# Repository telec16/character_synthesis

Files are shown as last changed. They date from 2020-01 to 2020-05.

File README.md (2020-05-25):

# Character Synthesis using Fourier Transform

Based on http://www.glensstuff.com/fouriersynthchargen/fouriersynthchargen.htm

## Front Panel

The front panel was made with Galva ( http://www.f5bu.fr/galva-download/ ), in French.

## Clock generation board

~/!\ DIVoddN is not synthetizable with Lattice LSE. I use Synplify Pro.~ Actually I don't know what's going on, but it does not correspond to the simulation. The hardware tests show no errors.

### FPGA pinmap

| Name 		| Pin Number | Pin Name | Location  |
|---|---|---|---|
| clk_1M2	| 13		 | PCLKT2_1	| X1.3		|
| clrn		| 14		 | PCLKC2_1	| J4.1		|
| clk_20k	| 8			 | CSSPIN	| J2.5		|
| clk_40k	| 9			 | MCLK		| J2.4		|
| clk_60k	| 10		 | SPISO	| J2.3		|
| clk_80k	| 11		 | PCLKT2_0	| J2.2		|
| clk_100k	| 12		 | PCLKC2_0	| J2.1		|
| E1A		| 16		 | SN		| SW1.1		|
| E1B		| 17		 | SPISI	| SW1.3		|
| E2A		| 20		 | PCLKC1_0	| SW2.1		|
| E2B		| 21		 | PCLKT1_0	| SW2.3		|
| blanking  | 5			 | PCLKC3_0	| J2.6		|
| led 		| 23		 | DONE		| D2		|
| pin1		| 28		 | SCL		| J2.8		|
| pin2		| 4			 | PCLKT3_0	| J2.7		|
| TDO		| 1			 | TDO		| J1.5		|
| TDI		| 32		 | TDI		| J1.3		|
| TCK		| 30		 | TCK		| J1.2		|
| TMS		| 29		 | TMS		| J1.1		|

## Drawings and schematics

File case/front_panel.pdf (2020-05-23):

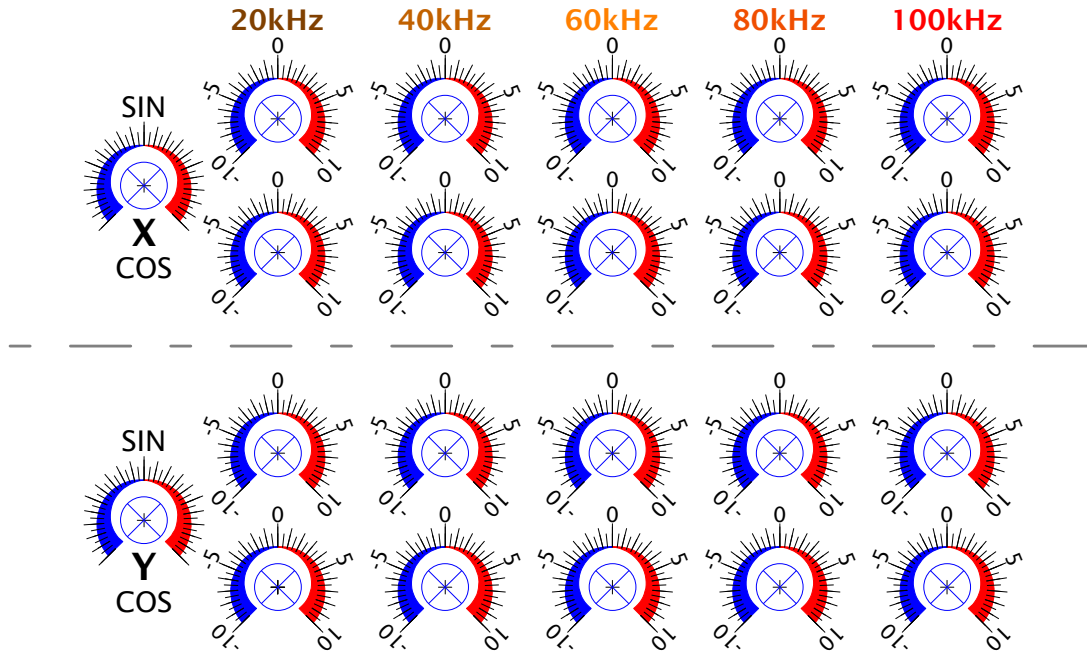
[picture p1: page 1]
20kHz; 40kHz; 60kHz; 80kHz; 100kHz; SIN; COS

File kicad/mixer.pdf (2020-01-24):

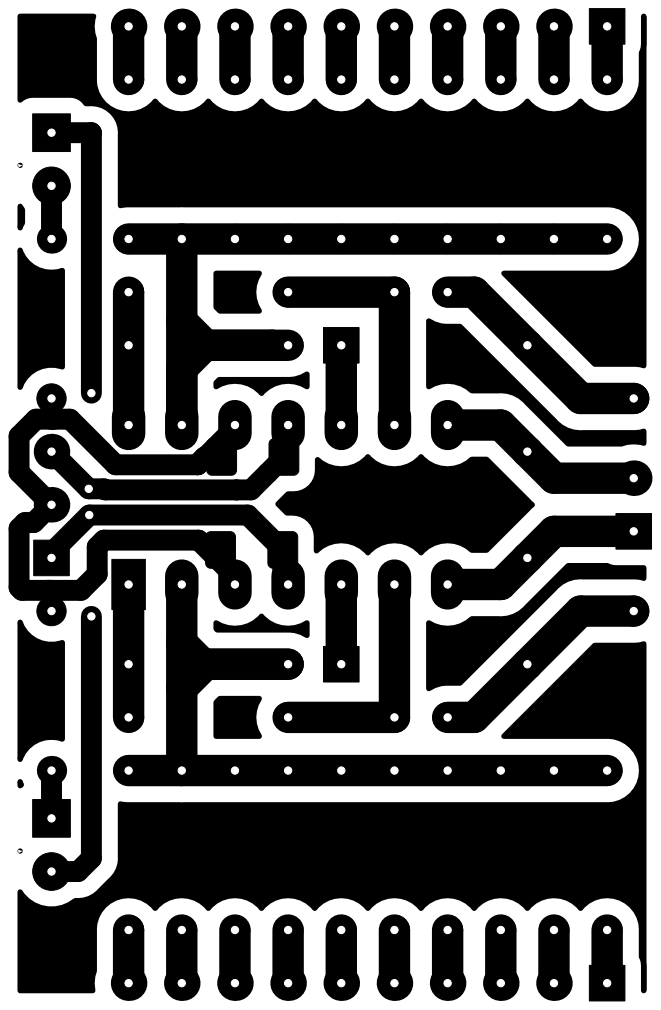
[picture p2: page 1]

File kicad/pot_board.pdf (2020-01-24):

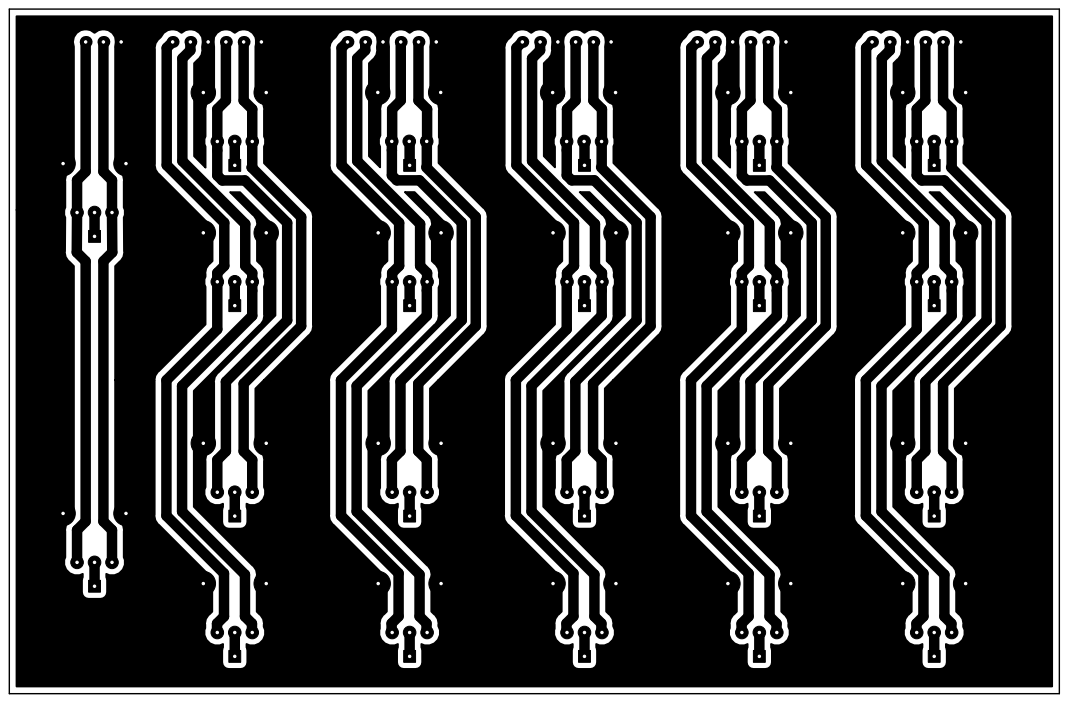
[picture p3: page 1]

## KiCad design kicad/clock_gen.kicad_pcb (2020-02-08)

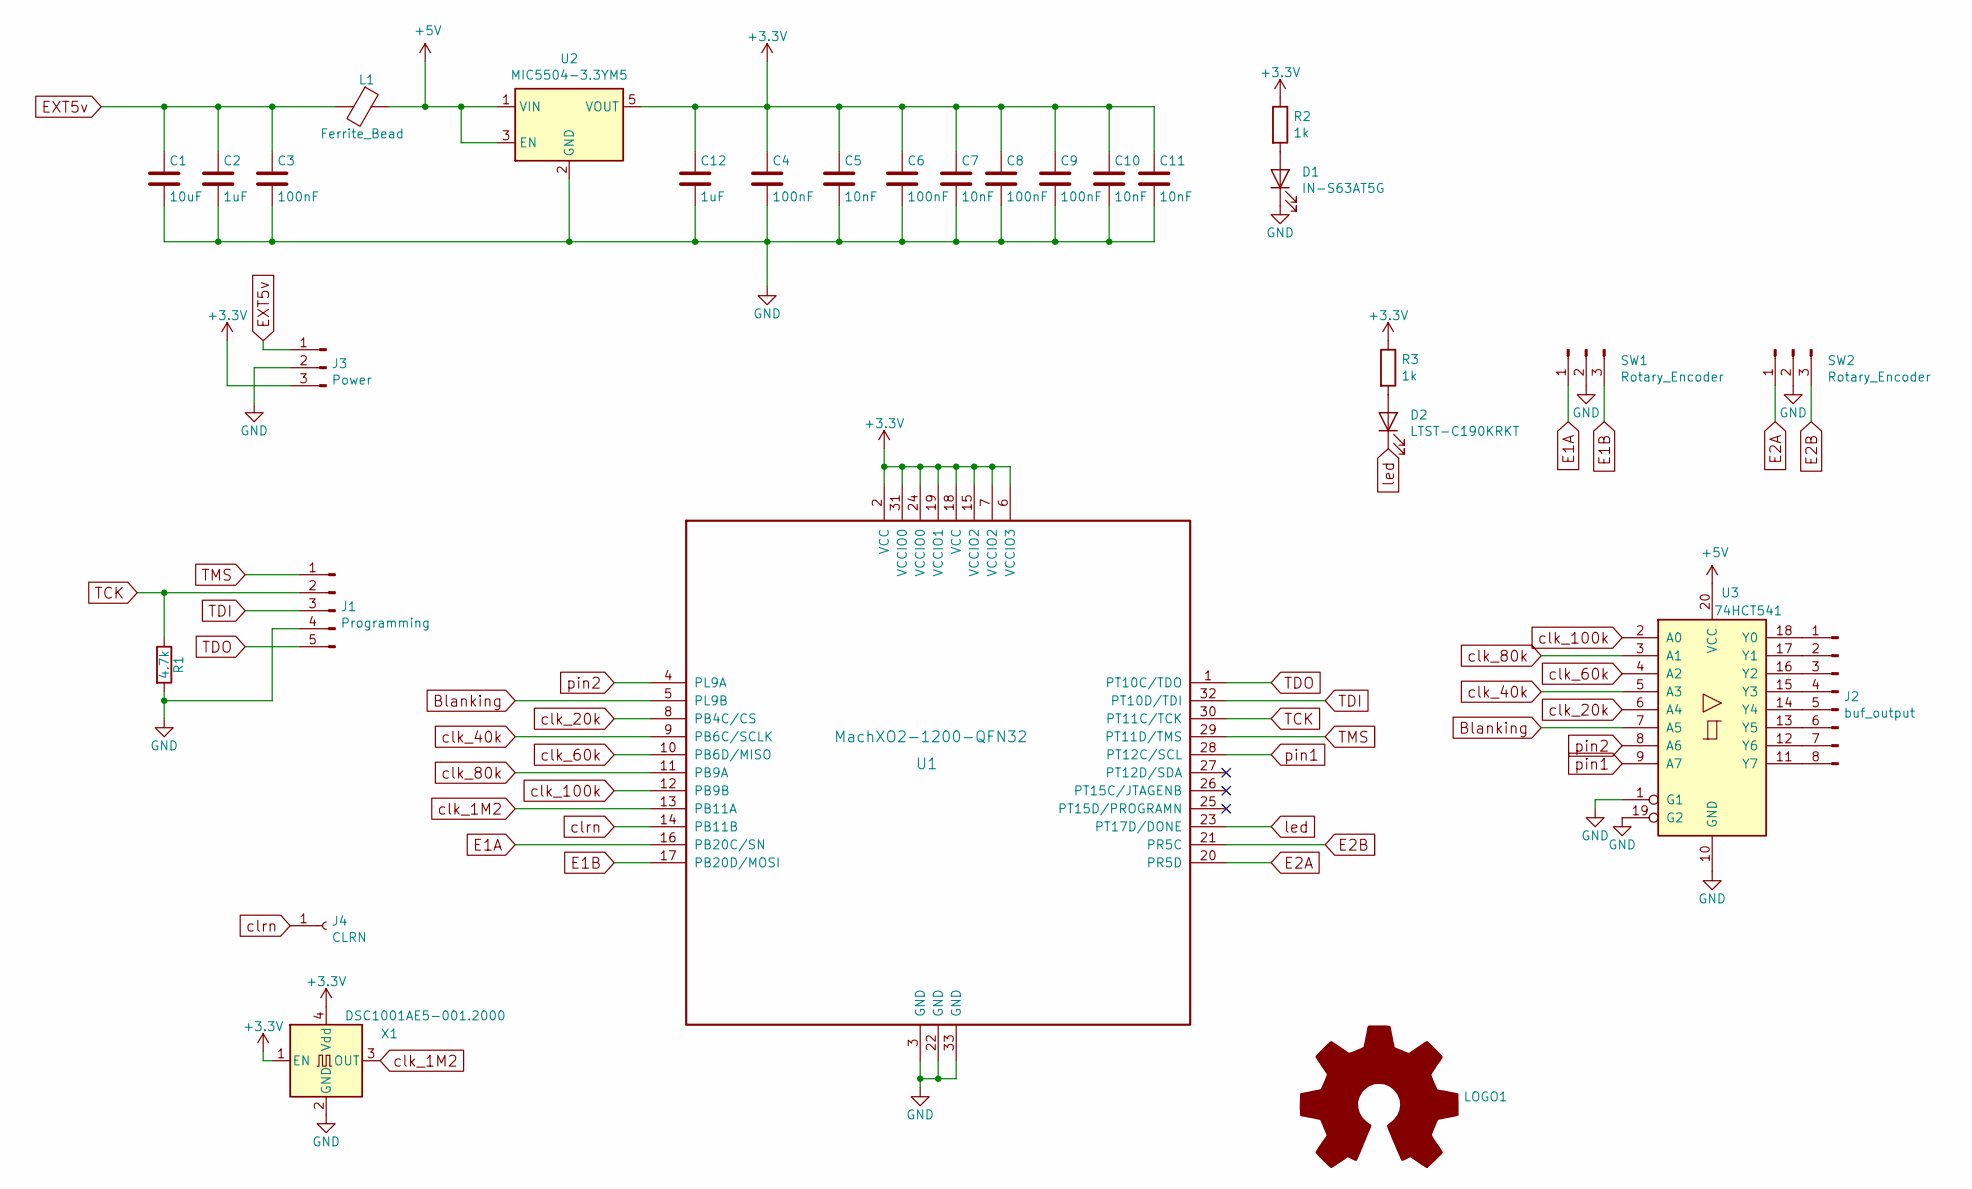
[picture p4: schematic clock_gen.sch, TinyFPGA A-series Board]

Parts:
C1: 10uF; C_0603_1608Metric
C2, C12: 1uF; C_0603_1608Metric
C3, C4, C6, C8, C9: 100nF; C_0603_1608Metric
C5, C7, C10, C11: 10nF; C_0603_1608Metric
D1: IN-S63AT5G; LED_0603_1608Metric
D2: LTST-C190KRKT; LED_0603_1608Metric
J1: Programming; PinHeader_1x05_P2.54mm_Vertical
J2: buf_output; PinHeader_1x08_P1.27mm_Vertical
J3: Power; PinHeader_1x03_P1.27mm_Vertical
J4: CLRN; PinHeader_1x01_P1.27mm_Vertical
L1: Ferrite_Bead; L_0603_1608Metric
LOGO1: Logo_Open_Hardware_Large; clk
R1: 4.7k; R_0603_1608Metric
R2, R3: 1k; R_0603_1608Metric
SW1, SW2: Rotary_Encoder; PinHeader_1x03_P1.27mm_Vertical
U1: MachXO2-1200-QFN32; QFN-32-1EP_5x5mm_P0.5mm_EP3.1x3.1mm_ThermalVias
U2: MIC5504-3.3YM5; SOT-23-5
U3: 74HCT541; SOIC-20W_7.5x12.8mm_P1.27mm
X1: DSC1001AE5-001.2000; Oscillator_SMD_EuroQuartz_XO91-4Pin_7.0x5.0mm

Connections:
+3V3: C4.1, C5.1, C6.1, C7.1, C8.1, C9.1, C10.1, C11.1, C12.1, J3.3, R2.1, R3.1, U1.2 (VCC), U1.6 (VCCIO3), U1.7 (VCCIO2), U1.15 (VCCIO2), U1.18 (VCC), U1.19 (VCCIO1), U1.24 (VCCIO0), U1.31 (VCCIO0), U2.5 (VOUT), X1.1 (EN), X1.4 (Vdd)
+5V: L1.1, U2.1 (VIN), U2.3 (EN), U3.20 (VCC)
Blanking: U1.5 (PL9B), U3.7 (A5)
E1A: SW1.1, U1.16 (PB20C/SN)
E1B: SW1.3, U1.17 (PB20D/MOSI)
E2A: SW2.1, U1.20 (PR5D)
E2B: SW2.3, U1.21 (PR5C)
EXT5v: C1.1, C2.1, C3.1, J3.1, L1.2
GND: C1.2, C2.2, C3.2, C4.2, C5.2, C6.2, C7.2, C8.2, C9.2, C10.2, C11.2, C12.2, D1.1 (K), J1.4, J3.2, R1.2, SW1.2, SW2.2, U1.3 (GND), U1.22 (GND), U1.33 (GND), U2.2 (GND), U3.1 (G1), U3.10 (GND), U3.19 (G2), X1.2 (GND)
unnamed: D1.2 (A), R2.2
unnamed: D2.2 (A), R3.2
unnamed: J2.1, U3.18 (Y0)
unnamed: J2.2, U3.17 (Y1)
unnamed: J2.3, U3.16 (Y2)
unnamed: J2.4, U3.15 (Y3)
unnamed: J2.5, U3.14 (Y4)
unnamed: J2.6, U3.13 (Y5)
unnamed: J2.7, U3.12 (Y6)
unnamed: J2.8, U3.11 (Y7)
TCK: J1.2, R1.1, U1.30 (PT11C/TCK)
TDI: J1.3, U1.32 (PT10D/TDI)
TDO: J1.5, U1.1 (PT10C/TDO)
TMS: J1.1, U1.29 (PT11D/TMS)
clk_1M2: U1.13 (PB11A), X1.3 (OUT)
clk_20k: U1.8 (PB4C/CS), U3.6 (A4)
clk_40k: U1.9 (PB6C/SCLK), U3.5 (A3)
clk_60k: U1.10 (PB6D/MISO), U3.4 (A2)
clk_80k: U1.11 (PB9A), U3.3 (A1)
clk_100k: U1.12 (PB9B), U3.2 (A0)
clrn: J4.1, U1.14 (PB11B)
led: D2.1 (K), U1.23 (PT17D/DONE)
pin1: U1.28 (PT12C/SCL), U3.9 (A7)
pin2: U1.4 (PL9A), U3.8 (A6)

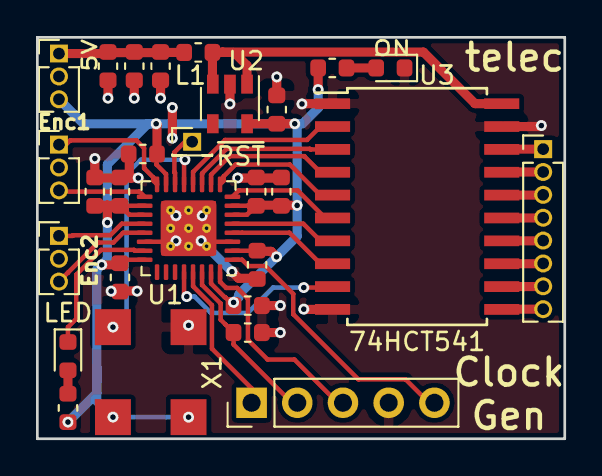
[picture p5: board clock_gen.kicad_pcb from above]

Board: 2 copper layers, 29.3 x 22.3 mm, 29 parts (1 on the bottom side), 33 nets.

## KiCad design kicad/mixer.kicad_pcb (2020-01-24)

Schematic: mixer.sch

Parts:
C1, C2: 1u; C_1206_3216Metric_Pad1.42x1.75mm_HandSolder
D1, D2: LED; LED_D4.0mm
J1: Power; PinHeader_1x03_P2.54mm_Vertical
J2: X input; PinHeader_1x10_P2.54mm_Vertical
J3: X offset; PinHeader_1x01_P2.54mm_Vertical
J4: Y input; PinHeader_1x10_P2.54mm_Vertical
J5: Y offset; PinHeader_1x01_P2.54mm_Vertical
J6: Output; PinHeader_1x02_P2.54mm_Vertical
R1, R2: 3k3; R_Axial_DIN0204_L3.6mm_D1.6mm_P7.62mm_Horizontal
R3, R4, R5, R6, R7, R8, R9, R10, R11, R12, R13, R16, R17, R18, R19, R20, R21, R22, R23, R24, R25, R26: 100k; R_Axial_DIN0204_L3.6mm_D1.6mm_P7.62mm_Horizontal
R14, R27: 1k; R_Axial_DIN0204_L3.6mm_D1.6mm_P2.54mm_Vertical
R15, R28: 1k; R_Axial_DIN0204_L3.6mm_D1.6mm_P7.62mm_Horizontal
RV1, RV2: 10k; Potentiometer_Bourns_3386F_Vertical
U1: TL084; DIP-14_W7.62mm_LongPads

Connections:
+15V: C1.1, D1.2 (A), J1.1, U1.4
-15V: C2.2, D2.1 (K), J1.3, U1.11
/X: J6.1, RV1.3, U1.7
/Xi: R3.1, R4.1, R5.1, R6.1, R7.1, R8.1, R9.1, R10.1, R11.1, R12.1, R13.2, U1.2
/Xo: J3.1, U1.5
/Y: J6.2, RV2.1, U1.8
/Yi: R16.1, R17.1, R18.1, R19.1, R20.1, R21.1, R22.1, R23.1, R24.1, R25.1, R26.2, U1.13
/Yo: J5.1, U1.10
GND: C1.2, C2.1, J1.2, R1.1, R2.1, U1.3, U1.12
unnamed: D1.1 (K), R1.2
unnamed: D2.2 (A), R2.2
unnamed: J2.1, R3.2
unnamed: J2.2, R5.2
unnamed: J2.3, R7.2
unnamed: J2.4, R9.2
unnamed: J2.5, R11.2
unnamed: J2.6, R4.2
unnamed: J2.7, R6.2
unnamed: J2.8, R8.2
unnamed: J2.9, R10.2
unnamed: J2.10, R12.2
unnamed: J4.1, R16.2
unnamed: J4.2, R18.2
unnamed: J4.3, R20.2
unnamed: J4.4, R22.2
unnamed: J4.5, R24.2
unnamed: J4.6, R17.2
unnamed: J4.7, R19.2
unnamed: J4.8, R21.2
unnamed: J4.9, R23.2
unnamed: J4.10, R25.2
unnamed: R13.1, R15.2, U1.1
unnamed: R14.1, RV1.1, RV1.2
unnamed: R14.2, R15.1, U1.6
unnamed: R26.1, R28.2, U1.14
unnamed: R27.1, RV2.2, RV2.3
unnamed: R27.2, R28.1, U1.9

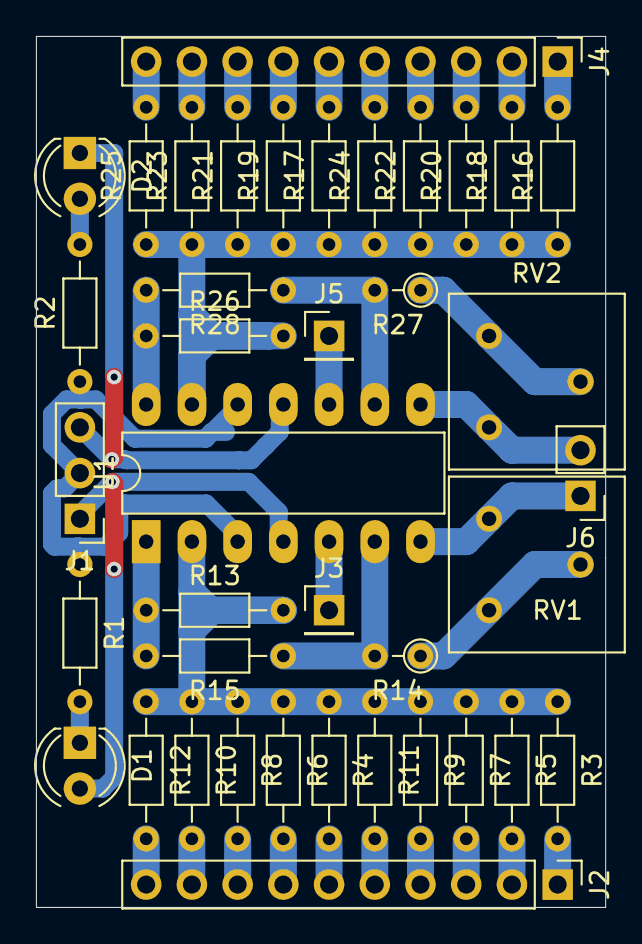
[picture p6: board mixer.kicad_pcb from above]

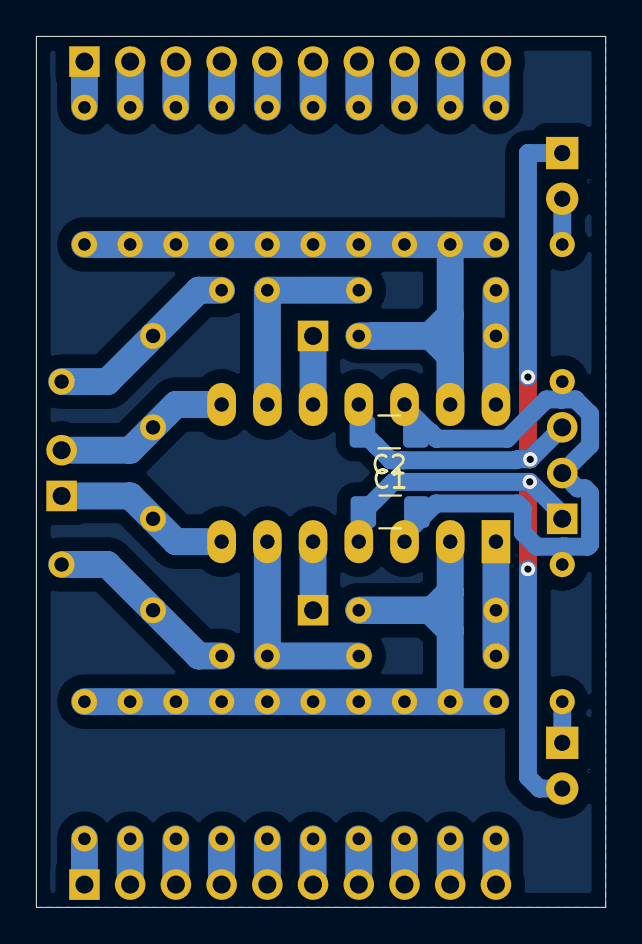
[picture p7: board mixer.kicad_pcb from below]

Board: 2 copper layers, 31.6 x 48.4 mm, 41 parts (2 on the bottom side), 37 nets.

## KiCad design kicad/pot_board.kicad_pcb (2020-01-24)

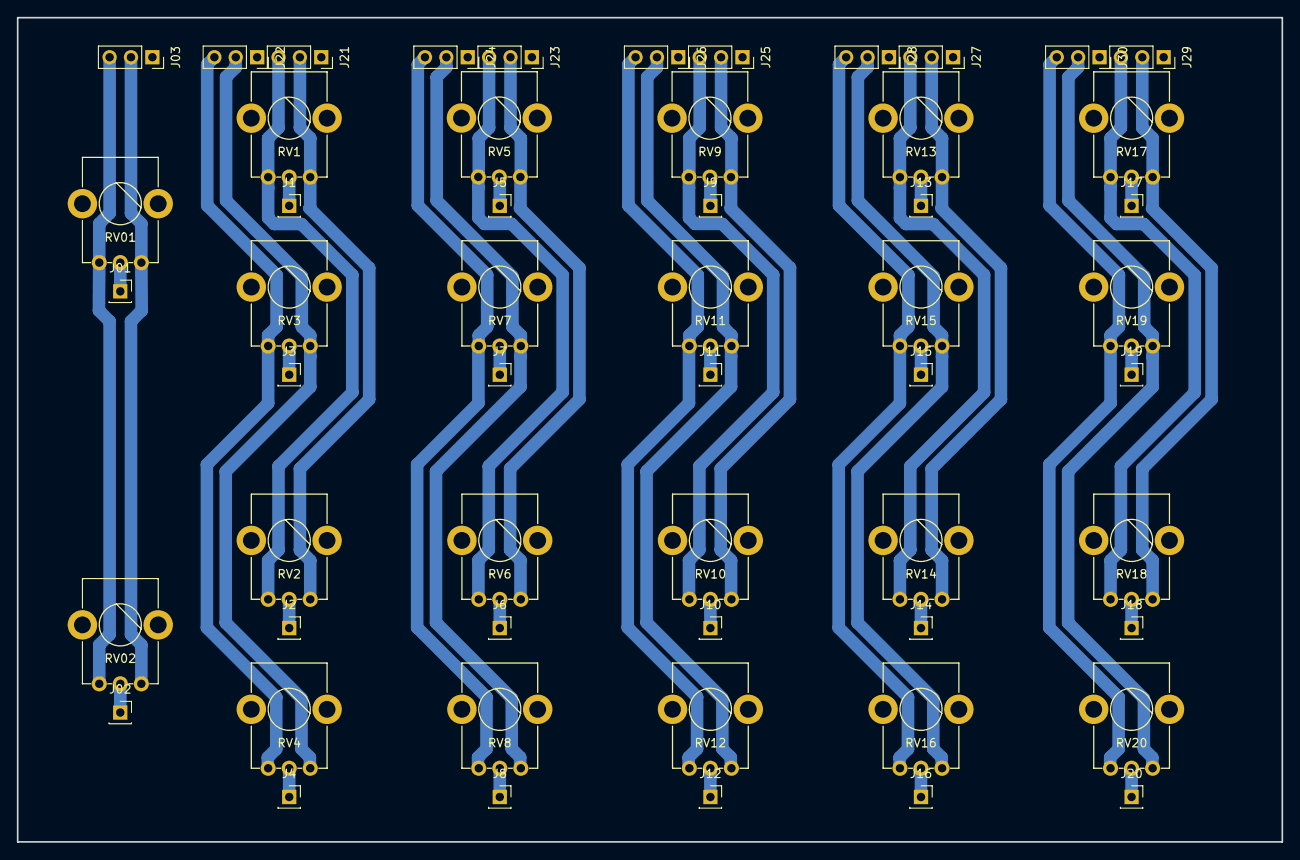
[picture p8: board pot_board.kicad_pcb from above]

Board: 2 copper layers, 150.2 x 97.9 mm, 55 parts (0 on the bottom side), 45 nets.

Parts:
J01, J1, J02, J2, J3, J4, J5, J6, J7, J8, J9, J10, J11, J12, J13, J14, J15, J16, J17, J18, J19, J20: OUT; PinSocket_1x01_P2.54mm_Vertical
J03, J21, J22, J23, J24, J25, J26, J27, J28, J29, J30: IN; PinSocket_1x03_P2.54mm_Vertical
RV01, RV1, RV02, RV2, RV3, RV4, RV5, RV6, RV7, RV8, RV9, RV10, RV11, RV12, RV13, RV14, RV15, RV16, RV17, RV18, RV19, RV20: 10k; PTV09A

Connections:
GND: J03.1, J21.1, J22.1, J23.1, J24.1, J25.1, J26.1, J27.1, J28.1, J29.1, J30.1, RV01.4, RV1.4, RV02.4, RV2.4, RV3.4, RV4.4, RV5.4, RV6.4, RV7.4, RV8.4, RV9.4, RV10.4, RV11.4, RV12.4, RV13.4, RV14.4, RV15.4, RV16.4, RV17.4, RV18.4, RV19.4, RV20.4
unnamed: J01.1, RV01.2
unnamed: J1.1, RV1.2
unnamed: J02.1, RV02.2
unnamed: J2.1, RV2.2
unnamed: J3.1, RV3.2
unnamed: J03.2, RV01.3, RV02.3
unnamed: J03.3, RV01.1, RV02.1
unnamed: J4.1, RV4.2
unnamed: J5.1, RV5.2
unnamed: J6.1, RV6.2
unnamed: J7.1, RV7.2
unnamed: J8.1, RV8.2
unnamed: J9.1, RV9.2
unnamed: J10.1, RV10.2
unnamed: J11.1, RV11.2
unnamed: J12.1, RV12.2
unnamed: J13.1, RV13.2
unnamed: J14.1, RV14.2
unnamed: J15.1, RV15.2
unnamed: J16.1, RV16.2
unnamed: J17.1, RV17.2
unnamed: J18.1, RV18.2
unnamed: J19.1, RV19.2
unnamed: J20.1, RV20.2
unnamed: J21.2, RV1.3, RV2.3
unnamed: J21.3, RV1.1, RV2.1
unnamed: J22.2, RV3.3, RV4.3
unnamed: J22.3, RV3.1, RV4.1
unnamed: J23.2, RV5.3, RV6.3
unnamed: J23.3, RV5.1, RV6.1
unnamed: J24.2, RV7.3, RV8.3
unnamed: J24.3, RV7.1, RV8.1
unnamed: J25.2, RV9.3, RV10.3
unnamed: J25.3, RV9.1, RV10.1
unnamed: J26.2, RV11.3, RV12.3
unnamed: J26.3, RV11.1, RV12.1
unnamed: J27.2, RV13.3, RV14.3
unnamed: J27.3, RV13.1, RV14.1
unnamed: J28.2, RV15.3, RV16.3
unnamed: J28.3, RV15.1, RV16.1
unnamed: J29.2, RV17.3, RV18.3
unnamed: J29.3, RV17.1, RV18.1
unnamed: J30.2, RV19.3, RV20.3
unnamed: J30.3, RV19.1, RV20.1

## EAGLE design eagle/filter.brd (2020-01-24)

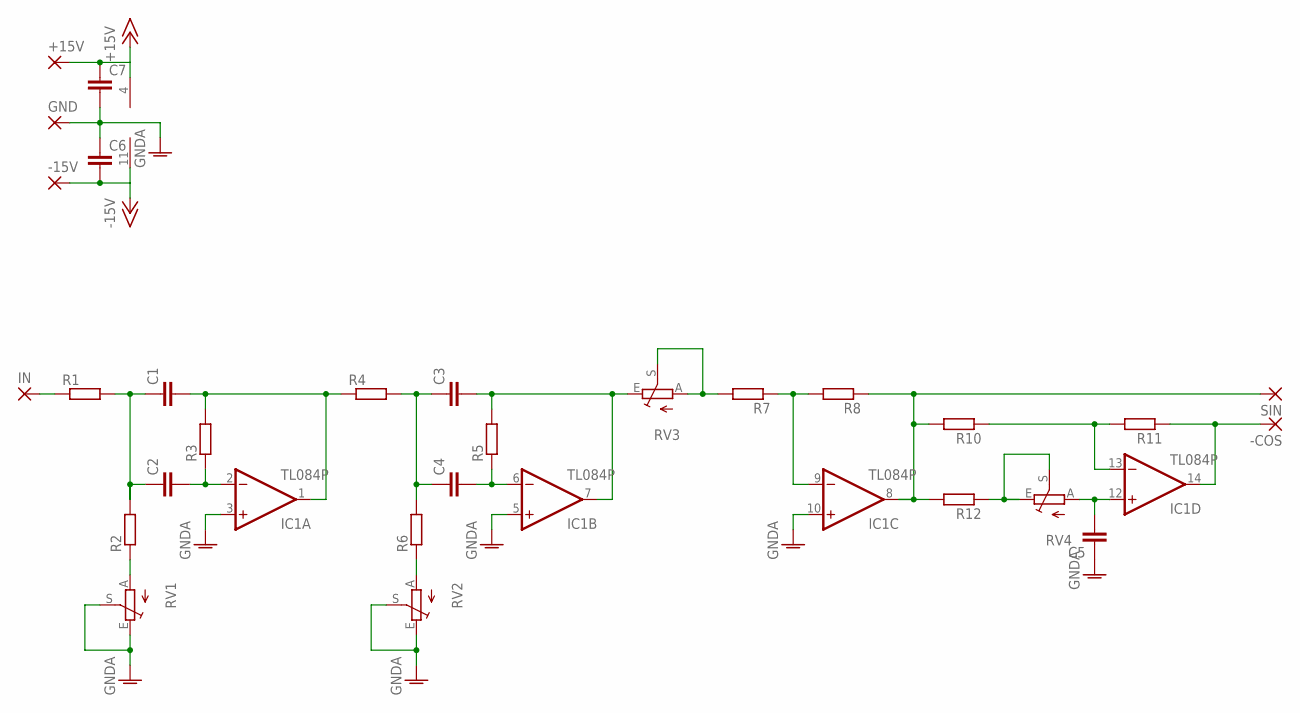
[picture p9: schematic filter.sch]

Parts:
+15V: 2,15/1,0
-15V: 2,15/1,0
-COS: 2,15/1,0
C1, C2, C3, C4, C5: C-EU025-025X050; C025-025X050
C6, C7: C-EU050-030X075; C050-030X075
GND: 2,15/1,0
IC1: TL084P; DIL14
IN: 2,15/1,0
R1, R2, R3, R4, R5, R6, R7, R8, R10, R11, R12: R-EU_0309/V; 0309V
RV1, RV2, RV3, RV4: TRIM_EU-RJ9W; RJ9W
SIN: 2,15/1,0

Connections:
+15V: +15V.1, C7.1, IC1.4 (V+)
-15V: -15V.1, C6.2, IC1.11 (V-)
GNDA: C5.1, C6.1, C7.2, GND.1, IC1.3 (+IN), IC1.5 (+IN), IC1.10 (+IN), RV1.E, RV1.S, RV2.E, RV2.S
unnamed: R2.1, RV1.A
unnamed: C1.1, C2.1, R1.2, R2.2
unnamed: -COS.1, IC1.14 (OUT), R11.1
unnamed: C1.2, IC1.1 (OUT), R3.2, R4.1
unnamed: C2.2, IC1.2 (-IN), R3.1
unnamed: IN.1, R1.1
unnamed: R6.1, RV2.A
unnamed: C3.1, C4.1, R4.2, R6.2
unnamed: C3.2, IC1.7 (OUT), R5.2, RV3.E
unnamed: C4.2, IC1.6 (-IN), R5.1
unnamed: R7.2, RV3.A, RV3.S
unnamed: IC1.9 (-IN), R7.1, R8.2
unnamed: IC1.8 (OUT), R8.1, R10.2, R12.2, SIN.1
unnamed: IC1.13 (-IN), R10.1, R11.2
unnamed: R12.1, RV4.E, RV4.S
unnamed: C5.2, IC1.12 (+IN), RV4.A

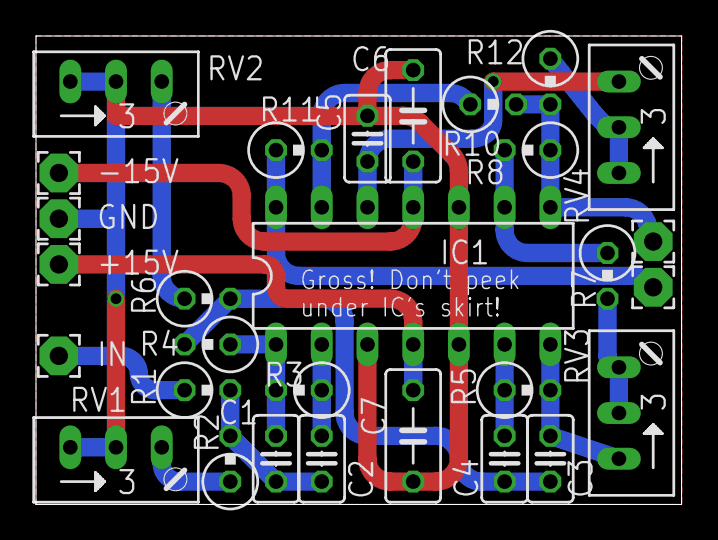
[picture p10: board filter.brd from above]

Board: 2 copper layers, 35.9 x 26.0 mm, 29 parts (0 on the bottom side), 19 nets.

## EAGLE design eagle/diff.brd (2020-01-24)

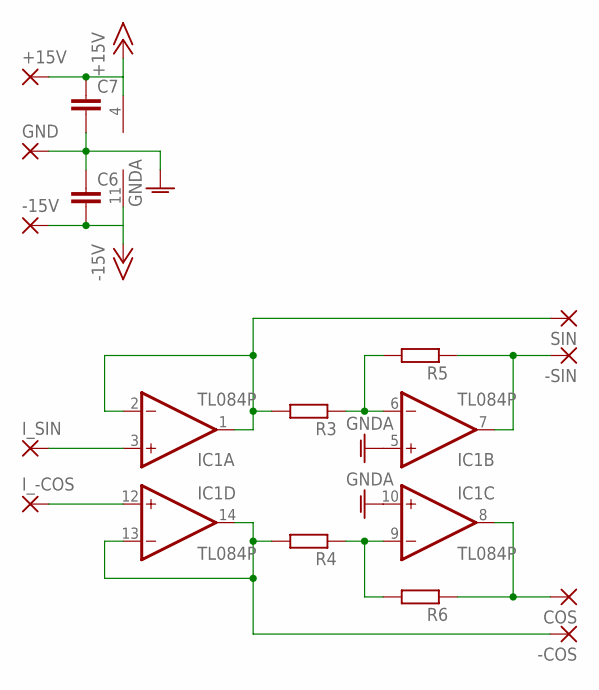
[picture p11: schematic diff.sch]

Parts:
+15V: 2,15/1,0
-15V: 2,15/1,0
-COS: 2,15/1,0
-SIN: 2,15/1,0
C6, C7: C-EU050-030X075; C050-030X075
COS: 2,15/1,0
GND: 2,15/1,0
IC1: TL084P; DIL14
I_-COS: 2,15/1,0
I_SIN: 2,15/1,0
R3, R4, R5, R6: R-EU_0309/V; 0309V
SIN: 2,15/1,0

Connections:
+15V: +15V.1, C7.1, IC1.4 (V+)
-15V: -15V.1, C6.2, IC1.11 (V-)
GNDA: C6.1, C7.2, GND.1, IC1.5 (+IN), IC1.10 (+IN)
unnamed: IC1.3 (+IN), I_SIN.1
unnamed: IC1.12 (+IN), I_-COS.1
unnamed: -COS.1, IC1.13 (-IN), IC1.14 (OUT), R4.2
unnamed: IC1.1 (OUT), IC1.2 (-IN), R3.2, SIN.1
unnamed: IC1.6 (-IN), R3.1, R5.2
unnamed: -SIN.1, IC1.7 (OUT), R5.1
unnamed: IC1.9 (-IN), R4.1, R6.2
unnamed: COS.1, IC1.8 (OUT), R6.1

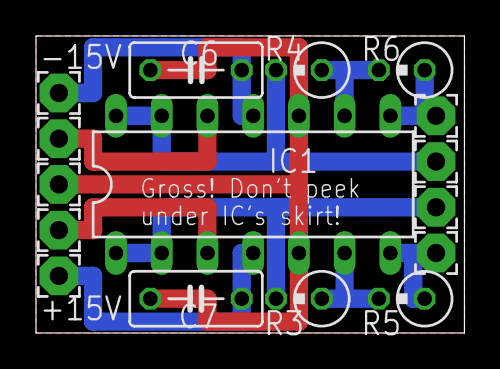
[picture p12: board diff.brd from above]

Board: 2 copper layers, 23.8 x 16.5 mm, 16 parts (0 on the bottom side), 11 nets.

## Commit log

2020-01-26 Kicad files for the clocks source
    [clock_gen.kicad_pcb, clock_gen.sch]
2020-02-08 Finished PCB
    [clock_gen.kicad_pcb, clock_gen.sch]
2020-05-23 clock gen Minimal Working Example (tested)
    [clock_gen.sch]
2020-05-23 Encoder structure
